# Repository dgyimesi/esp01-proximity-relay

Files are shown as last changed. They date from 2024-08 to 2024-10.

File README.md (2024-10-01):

# ESP01 Proximity Relay

Proximity sensor aided relay with HTTP API to my bathroom mirror lights.

Want a discrete light switch which can be operated by reaching out to your light source?
Forgot to switch off the bathroom mirror light, but too lazy to get up from the bed?
Here you go.

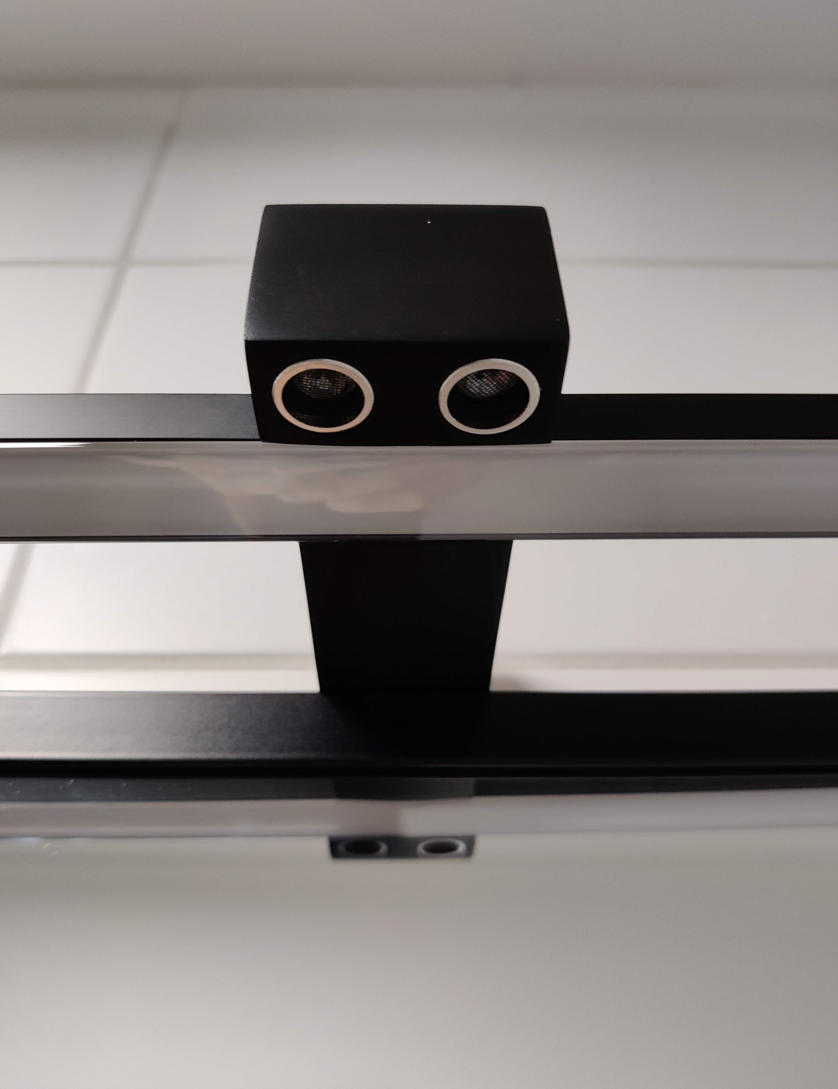
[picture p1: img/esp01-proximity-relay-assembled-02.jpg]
Installed ESP01 Proximity Relay


See more [here](img/).

WIP:
- wiring diagram

## What you need

- Arduino Studio
- ESP8266-01
- JoyIt ESP-01S relay module (or clone)
- HC-SR04-4P ultrasonic distance sensor
- CH340 TTL-UART programmer (ideally with the flash button)
- soldering station
- some wires rated for your load
- (optional) Wago connectors
- (optional) 3D printer

## Configuration

Check out comments in the header section.

## API

| Endpoint | Action |
| --- | --- |
| /on | Closes the relay |
| /off | Opens the relay  |
| /api | ```{ "relayState": false, "distance": 64.89, "lastTriggerDistance": 22.48, "timeSinceLastTrigger": 274 }``` |

## Enclosure

If you happen to have [the same bathroom mirror lights](https://www.obi.at/zubehoer-fuer-spiegel/maximus-led-spiegelleuchte-esther-50-cm-schwarz/p/8040370) as me, knock yourself out.

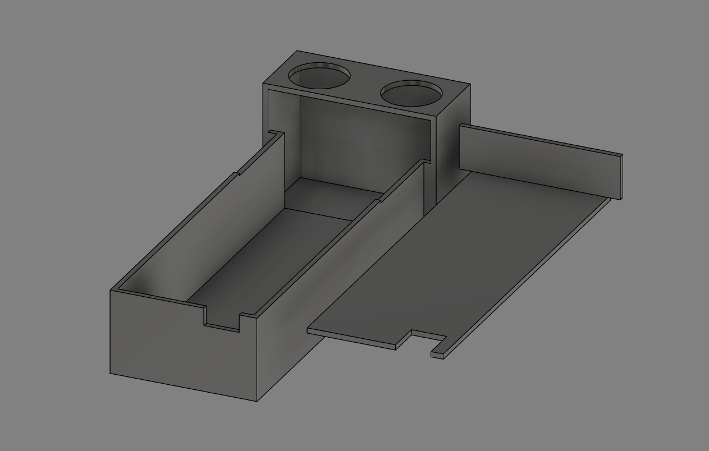
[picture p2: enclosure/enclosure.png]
ESP01 Proximity Relay enclosure


## Flash

You might run into connectivity problems with the most recent CH340 driver. Version ```08/08/2014, 3.4.2014.08``` worked for me as teh internetz suggested.

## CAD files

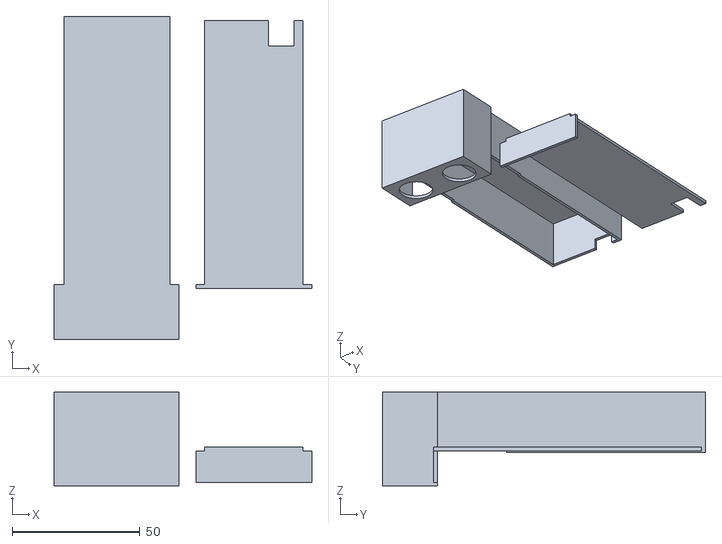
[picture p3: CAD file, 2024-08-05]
enclosure/enclosure.stl
101.0 x 126.5 x 36.7

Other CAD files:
enclosure/enclosure.f3d

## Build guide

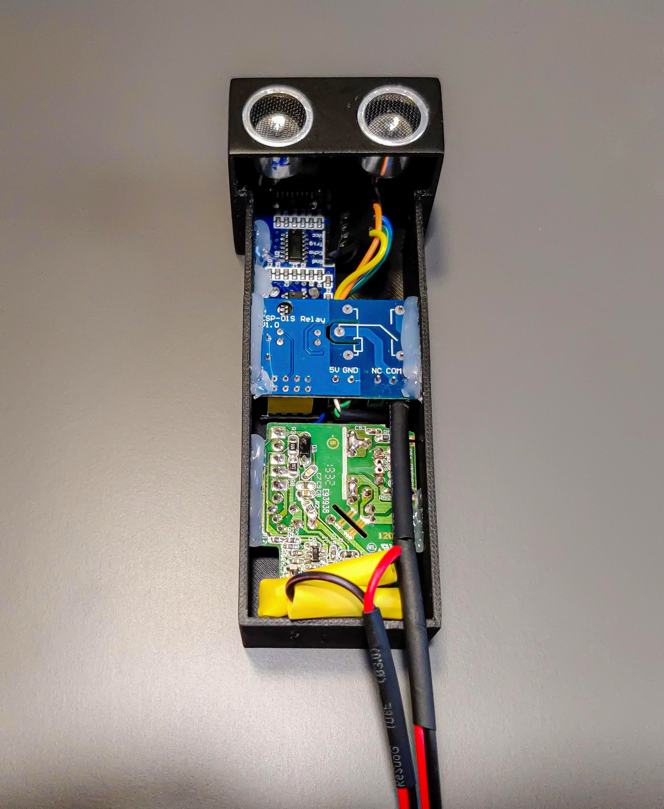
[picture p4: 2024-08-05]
img/esp01-proximity-relay-assembly-00.jpg

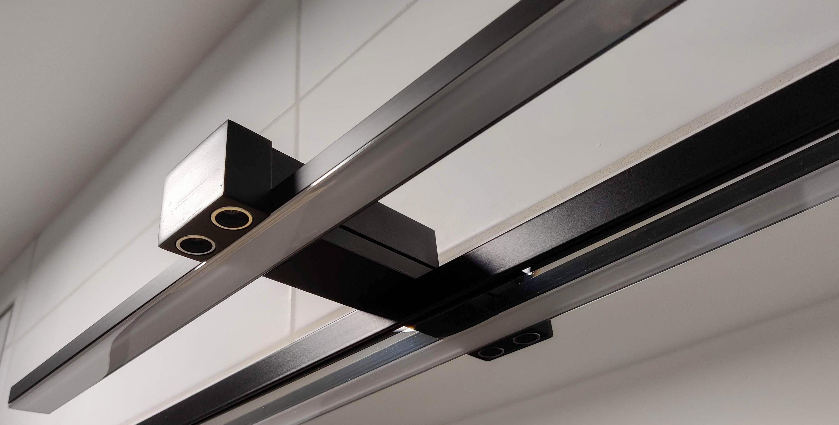
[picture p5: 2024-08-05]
img/esp01-proximity-relay-assembled-01.jpg

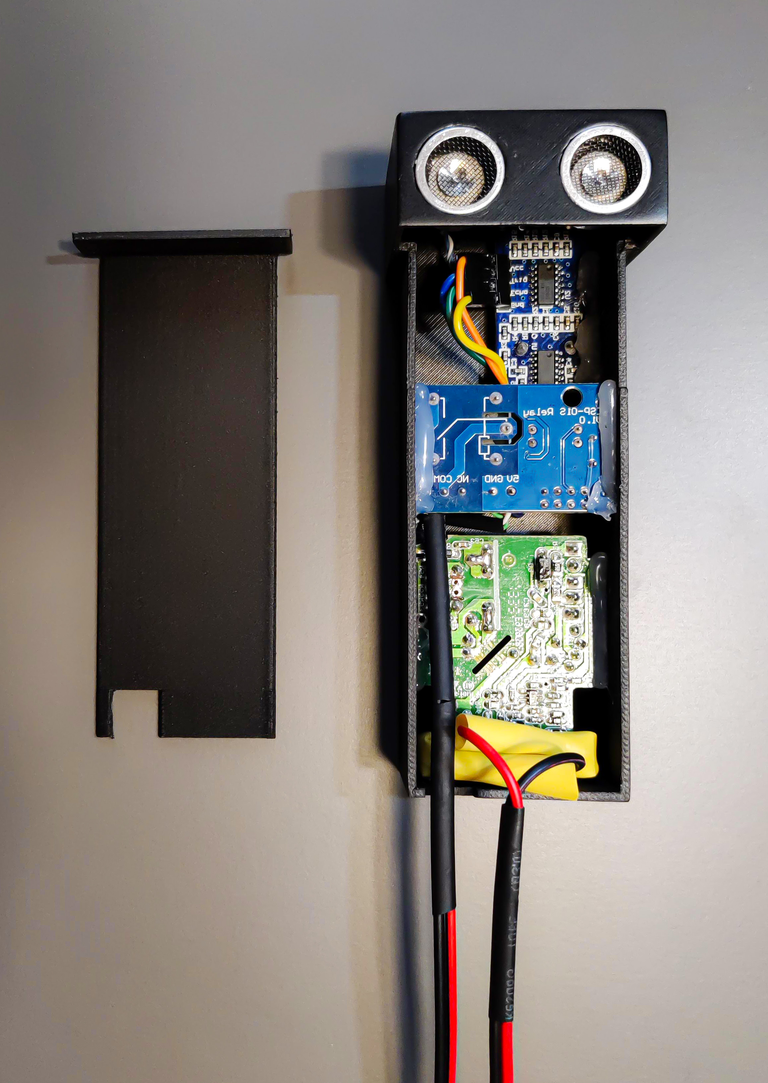
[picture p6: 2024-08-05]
img/esp01-proximity-relay-assembly-01.jpg

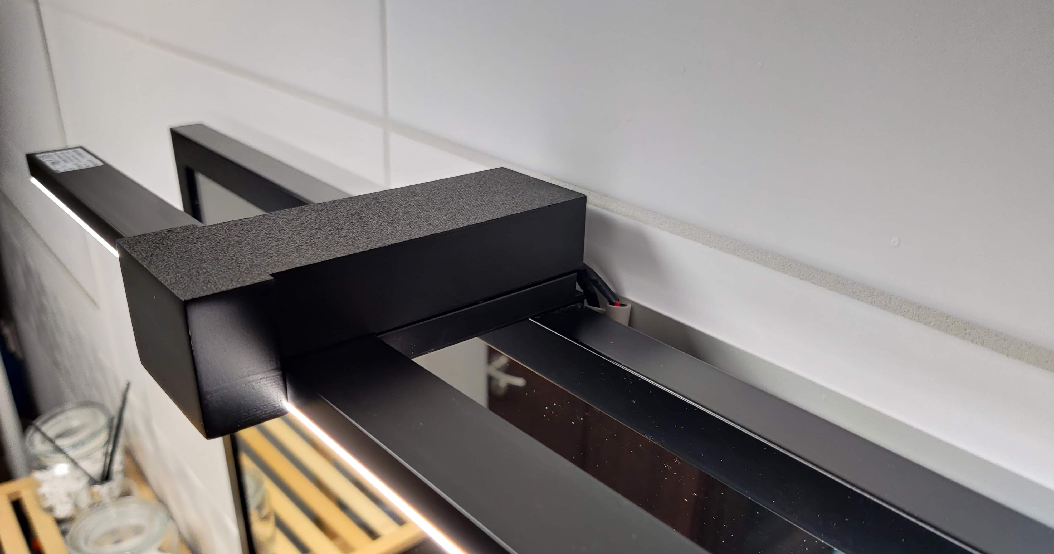
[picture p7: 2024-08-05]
img/esp01-proximity-relay-assembled-00.jpg

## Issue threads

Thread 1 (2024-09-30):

False triggers

dgyimesi, 2024-09-30:
There are occasional false positive detections which turn on the relay.
The culprit might be a missing 60ms delay suggested in the sensor library: https://github.com/gamegine/HCSR04-ultrasonic-sensor-lib

dgyimesi, 2024-10-01:
Fixed with [1.0.0](https://github.com/dgyimesi/esp01-proximity-relay/releases/tag/1.0.0)

Closed 2024-10-01.

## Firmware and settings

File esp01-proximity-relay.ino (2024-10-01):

#include <ESP8266WiFi.h>
#include <MKL_HCSR04.h>

// Debug: setting to false enables RX/TX as relay I/O, otherwise RX/TX is used for serial monitor.
#define DEBUG false

#if DEBUG == true
#define DEBUG_PRINT(x) Serial.print(x)
#define DEBUG_PRINTLN(x) Serial.println(x)
#else
#define DEBUG_PRINT(x)
#define DEBUG_PRINTLN(x)
#endif

// WiFi
#define WIFI_SSID "v3rys3cr3t"
#define WIFI_PASSWORD "v3rys3cr3t"
#define WIFI_HTTP_PORT 80
#define WIFI_STATUS_CHECK_INTERVAL 1000

// Relay
#define RELAY_PIN 0
#define RELAY_STATE_DEFAULT HIGH
#define RELAY_MODULE_NAME "Bathroom Mirror Light"

// Measurement
// NOTE: each measurement can take ~25ms + 75ms delay added to prevent trigger to echo leakage.
// Use multiple measurements (DISTANCE_MEASUREMENT_COUNT > 1) if you experience inaccuracies.
// Otherwise go with 250ms (DISTANCE_MEASUREMENT_INTERVAL_MS) to get a nice responsivity.
#define DISTANCE_MEASUREMENT_COUNT 3
#define DISTANCE_MEASUREMENT_INTERVAL_MS 0
#define DISTANCE_TRIGGER_ZONE_CM 25
#define DISTANCE_SENSOR_PIN_TRIGGER 1
#define DISTANCE_SENSOR_PIN_ECHO 3

// Prepare for var!
unsigned long timeNow = 0;
unsigned long timeSinceLastTrigger = 0;
unsigned long timeReportDistance = 0;

int relayState = RELAY_STATE_DEFAULT;

bool isApiRequest = false;
bool isLocked = false;

float distance = 0;
float lastMeasuredDistance = 0;
float lastTriggerDistance = 0;

WiFiServer server(WIFI_HTTP_PORT);
MKL_HCSR04 hc(DISTANCE_SENSOR_PIN_TRIGGER, DISTANCE_SENSOR_PIN_ECHO);

void setup() {
  // Setting up GPIO1/3.
  if (DEBUG == true) {
    // In debug mode we use RX/TX for Serial comms.
    Serial.begin(115200);
  } else {
    // Re-assign GPIO3/RX as input (echo).
    pinMode(3, INPUT);

    // Re-assign GPIO1/TX as output (trigger).
    pinMode(1, OUTPUT);
  }

  // Init status LED.
  pinMode(LED_BUILTIN, OUTPUT);
  digitalWrite(LED_BUILTIN, HIGH);

  // Init relay.
  pinMode(RELAY_PIN, OUTPUT);
  digitalWrite(RELAY_PIN, RELAY_STATE_DEFAULT);

  // Setup Wifi and HTTP server.
  setupWifi();
}

void loop() {
  timeNow = millis();
  
  // Evaluating distance from sensor.
  checkDistance();

  // /off: switches the relay OFF.
  // /on:  switches the relay ON.
  // /api: returns relay state, measured distance (cm), seconds since last trigger and last trigger distance (cm).
  handleRequests();
}

void setupWifi() {
  DEBUG_PRINT("Connecting to ");
  DEBUG_PRINT(WIFI_SSID);

  WiFi.hostname(RELAY_MODULE_NAME);
  WiFi.begin(WIFI_SSID, WIFI_PASSWORD);
  WiFi.setAutoReconnect(true);
  WiFi.persistent(true);

  while (WiFi.status() != WL_CONNECTED) {
    delay(1000);

    DEBUG_PRINT(".");
  }

  DEBUG_PRINTLN();

  switch (WiFi.status()) {
    case WL_NO_SSID_AVAIL:
      DEBUG_PRINTLN("Configured SSID cannot be reached");

      digitalWrite(LED_BUILTIN, HIGH);

      break;
    case WL_CONNECTED:
      DEBUG_PRINTLN("Connection successfully established");

      digitalWrite(LED_BUILTIN, LOW);

      break;
    case WL_CONNECT_FAILED:
      DEBUG_PRINTLN("Connection failed");

      digitalWrite(LED_BUILTIN, HIGH);

      break;
  }

  // Start HTTP server.
  server.begin();

  DEBUG_PRINT("Listening on ");
  DEBUG_PRINTLN(WiFi.localIP());

  digitalWrite(LED_BUILTIN, LOW);
}

void checkDistance() {
  if (timeNow - timeReportDistance >= DISTANCE_MEASUREMENT_INTERVAL_MS) {
    distance = 0;
    
    // Doing average because reported distance tends to fluctuate no matter the delay set between measurements.
    unsigned long timeMeasurementStart = millis();
    for (int i = 0; i < DISTANCE_MEASUREMENT_COUNT; i++) {
      distance += hc.dist();

      delay(75);
    }
    unsigned long timeMeasurementEnd = millis();
    
    DEBUG_PRINT("Measurement took ");
    DEBUG_PRINT(timeMeasurementEnd - timeMeasurementStart);
    DEBUG_PRINTLN(" ms");

    distance /= DISTANCE_MEASUREMENT_COUNT;
    
    bool approaching = distance - lastMeasuredDistance < 0;
    bool receding = distance - lastMeasuredDistance > 0;

    // Check if toggle isLocked can be opened (hand left the trigger zone).
    if (isLocked) {
      if (distance > DISTANCE_TRIGGER_ZONE_CM) {
        isLocked = false;
      }
    }

    // Hand approches trigger zone.
    if (!isLocked && approaching && distance < DISTANCE_TRIGGER_ZONE_CM) {
      relayState = 1 - relayState;

      // isLocked state until hand left is in the trigger zone [0cm, DISTANCE_TRIGGER_ZONE_CM].
      isLocked = true;

      lastTriggerDistance = distance;
      timeSinceLastTrigger = timeNow;
    }

    lastMeasuredDistance = distance;

    timeReportDistance = timeNow;

    digitalWrite(RELAY_PIN, relayState);
  }
}

void handleRequests() {
  // Check if a client has connected.
  WiFiClient client = server.available();
  if (!client) {
    return;
  }

  // Wait until the client sends some data.
  while (!client.available()) {
    delay(1);
  }

  DEBUG_PRINTLN("New client");

  isApiRequest = false;

  // Read the first line of the request.
  String request = client.readStringUntil('\r');
  DEBUG_PRINTLN(request);

  if (request.indexOf("/api") != -1) {
    DEBUG_PRINTLN("API request");

    isApiRequest = true;
  }

  if (request.indexOf("/on") != -1) {
    DEBUG_PRINTLN("Turning relay on");

    relayState = LOW;

    timeSinceLastTrigger = timeNow;

    digitalWrite(RELAY_PIN, relayState);
  }

  if (request.indexOf("/off") != -1) {
    DEBUG_PRINTLN("Turning relay off");

    relayState = HIGH;

    timeSinceLastTrigger = timeNow;

    digitalWrite(RELAY_PIN, relayState);
  }

  // Return the response.
  client.println("HTTP/1.1 200 OK");
  client.print("Content-Type: ");
  client.println(isApiRequest == true ? "application/json" : "text/html");
  client.println("Connection: close");
  client.println("");

  if (isApiRequest) {
    client.print("{ \"relayState\": ");
    client.print(relayState == LOW ? "true" : "false");
    client.print(", \"distance\": ");
    client.print(distance);
    client.print(", \"lastTriggerDistance\": ");
    client.print(lastTriggerDistance);
    client.print(", \"timeSinceLastTrigger\": ");
    client.print((int)((timeNow - timeSinceLastTrigger) / 1000));
    client.print(" }");
  } else {
    client.println("<!DOCTYPE HTML>");
    client.println("<html style='background: black; width: 100%;'>");
    client.println("<head><meta name='viewport' content='width=360'><title>");
    client.println(RELAY_MODULE_NAME);
    client.println("</title></head>");

    if (relayState == HIGH) {
      client.println("<a style='display: grid; margin: 10px auto; padding: 24px; align-content: space-evenly; font-family: Arial; font-size: 48px; border: 2px solid #fff; text-align: center; color: #fff; text-decoration: none; background: #666;' href='/off'>OFF</a>");
      client.println("<a style='display: grid; margin: 10px auto; padding: 24px; align-content: space-evenly; font-family: Arial; font-size: 48px; border: 2px solid #999; text-align: center; color: #999; text-decoration: none; background: #333;' href='/on'>ON</a>");
    } else {
      client.println("<a style='display: grid; margin: 10px auto; padding: 24px; align-content: space-evenly; font-family: Arial; font-size: 48px; border: 2px solid #999; text-align: center; color: #999; text-decoration: none; background: #333;' href='/off'>OFF</a>");
      client.println("<a style='display: grid; margin: 10px auto; padding: 24px; align-content: space-evenly; font-family: Arial; font-size: 48px; border: 2px solid #fff; text-align: center; color: #fff; text-decoration: none; background: #666;' href='/on'>ON</a>");
    }

    client.println("</html>");
    client.flush();
  }
}

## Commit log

2024-08-05 Add 3D model for enclosure; document.
    [enclosure.f3d, enclosure.stl]
2024-10-01 Do multiple measurements to prevent false triggers; add more API fields; add notes.
    [esp01-proximity-relay.ino]
